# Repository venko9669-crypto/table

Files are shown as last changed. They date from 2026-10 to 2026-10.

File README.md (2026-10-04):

# Сгъваема (навиваща се) маса

## Маса

| Параметър | Стойност |
|---|---|
| Плот | 500 × 700 мм |
| Височина | 415 мм |
| Товар | ~10 кг (разпределени) |
| Маса | ~2.7 кг (с алуминиеви тръби) |
| Сгъната на квадрат | ~190 × 190 мм при звената (150 × 150 в средата) × ~704 мм, всичко вътре |
| Навита | Ø~230 мм × ~704 мм, всичко вътре |

## Тръби

| Част | Размер | Бр. | Рязане |
|---|---|---|---|
| Лайсни (плот) | Ø10 × 700 мм | 26 | не се режат |
| Заключващи тръби (рамо) | Ø10 × 547 мм, 2 дупки Ø4 на 535 мм една от друга (на 6 мм от краищата) | 2 | от 700, остатък 153 |
| Крака | Ø15 × 650 мм | 4 | не се режат |

Тънки: трябват 28 от 29 (1 резерва). Дебели: 4 от 4.
Разпънката между пивотите от стария дизайн вече не трябва.

## Печат (PETG)

Готовите STL файлове са в папка `stl/` (и в `table_stl.zip`), вече обърнати
както се печатат, без подпори. Общо ~0.9 кг PETG.

| STL | Част | Бр. | Запълване |
|---|---|---|---|
| `link_outer.stl` | жълто звено | 22 | 40% gyroid |
| `link_inner.stl` | синьо звено | 24 | 40% |
| `link_end.stl` | крайно звено с вилка | 2 | 40% gyroid |
| `link_end_r.stl` | огледалното | 2 | 40% gyroid |
| `leg_shoe.stl` | обувчица | 4 | 25% gyroid |
| `leg_hub.stl` | вложка в центъра | 1 | 15% gyroid |
| `leg_mount.stl` | скоба на лайсна | 2 | 50% gyroid |
| `leg_mount_r.stl` | огледалната | 2 | 50% gyroid |

Слой 0.2 мм, 4 стени (3 стигат за звената - спестява ~15%).
Преди серията отпечатай по 1 жълто и 1 синьо звено и пробвай с тръба
(пресовата сглобка, процепа и щракването на заключващата тръба).
Дребни части: 2 пина Ø4 (щифт или болт M4), 8 винта M3 (самонарезни) за скобите.

### Оптимизации за печат

По препоръките за FDM дизайн (фаски по ръбовете на масата на принтера,
заоблени вътрешни ъгли, без надвеси над 45°):

- фаска 45° по всички ръбове, които лягат на принтера - няма „слонски крак“;
  фаските са на стъпала по 0.2 мм, точно колкото слоя (`print_helpers.scad`);
- фаски на входа на всички отвори - тръбите влизат по-лесно, а първият слой
  не стеснява отвора;
- заоблени ъгли R2 на звената и R3 във вътрешните ъгли на синьото звено;
- синьото звено е плоско отдолу (шайбичката е само отгоре) - ляга цялото
  на принтера, вместо да стои на два пръстена;
- обувчицата е тънка плоча + тяло само колкото ръкава (-21% материал);
- вложката е по-малка (Ø92 × 40) и се печата с 15% запълване (-20%).
  Пробвах вариант само с ръкави около краката, но те висят под 54° и
  не се печатат без подпори - затова тя остава сплескана сфера.

## Сглобяване

1. Сините звена се пъхат в процепите на жълтите, после лайсната се вкарва
   отвътре през жълтото и синьото до дъното на гнездото.
2. Скобите `mount` са щипки: щракват се отдолу на лайсни №4, 6, 21 и 23
   (броено от 1 до 26) и се затягат с M3. Пробий малка вдлъбнатина (Ø2.5)
   в лайсната под всеки винт - кракът бута скобата по лайсната и винтът
   трябва да опира в нея, а не само да стиска.
3. Заключващата тръба се закача с пин на `end` и се щраква в каналите като цип.
   Вторият пин в `end_r` я заключва.
4. Краката минават през вложката, горе влизат в скобите, долу в обувчиците.

## Сгъване на квадрат

Плотът се сгъва с горната повърхност навътре, като 4 стави се сгъват на 90°:
при лайсни №3, 10, 17 и 24. Получава се кутия 140 × 140 мм по осите на
лайсните. Шевът (двете крайни звена с вилките) е по средата на едната страна.

1. Вади се заключващата тръба (двата пина) и краката.
2. Развиват се винтовете M3 и скобите се откачват от лайсните.
3. Вътре се прибират: краката в 4-те ъгъла, вложката в единия край,
   обувчиците една след друга по средата, скобите в другия край,
   заключващите тръби покрай стената.
4. Кутията се стяга с колан или ластик.

Проверено в модела (`folded.scad`): в ъглите звената от двете страни са на
1 мм едно от друго, шевът не се удря, а нещата вътре не опират в звената
и едно в друго (свободно между звената по дължина: 666 мм, краката са 650).
Може и да се навие на руло (`rolled.scad`), Ø~230 мм.

## Проверка

`python3 check_fit.py` пресмята дължините, височините, разминаването на
краката, стабилността, натоварването и навиването. Важните резултати:

- Ъгъл на краката 35.6°, кръстосване на 201 мм. Краката се разминават във
  вложката с 3.9 мм.
- Продължението на оста на всеки крак минава точно през оста на лайсната,
  на която е скобата, така кракът не усуква лайсната.
- Обувчиците имат „пета“ 70 мм навън. С нея масата се накланя при ~7 кг
  натиск върху самия ръб на дългата страна (без нея беше ~3 кг).
- Товароносимост (разпределен товар, до провлачване на тръбите):
  ~31 кг с алуминиеви тръби, ~50 кг със стоманени. Най-слабото място е
  късото парче лайсна между скобата на крака и веригата. С коефициент на
  сигурност 2: **~15 кг (алуминий) / ~25 кг (стомана)**.
- Една лайсна Ø10×1 мм от алуминий носи до ~5 кг **точков** товар в
  средата (стомана ~8 кг). Лайсните не си делят точков товар, но 10 кг
  разпределени по целия плот са само ~0.4 кг на лайсна.

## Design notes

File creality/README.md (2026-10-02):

# Плочи за Creality (маса 220 × 220 мм)

Отвори .3mf файловете в Creality Print (или Orca/Cura). Всяка плоча е
подредена и центрирана, частите са отделни обекти.

| Файл | Части | Запълване | Бележки |
|---|---|---|---|
| `plate1_links_outer.3mf` | 22 жълти + 2 end + 2 end_r | 40% gyroid | brim 5 мм (високи и тесни) |
| `plate2_links_inner.3mf` | 24 сини | 40% | |
| `plate3_shoes.3mf` | 4 обувчици | 25% gyroid | |
| `plate4_hub.3mf` | 1 вложка | 15% gyroid | |
| `plate5_mounts.3mf` | 2 mount + 2 mount_r | 50% gyroid | brim 8 мм (81 мм високи) |

Общо за всички: PETG, дюза 0.4, слой 0.2 мм, 4 стени, 5 горни/долни слоя,
без подпори. PETG: дюза 235-245 °C, маса 75-80 °C, вентилатор 30-50%.

Преди да пуснеш plate1 и plate2 изцяло - отпечатай по 1 жълто и 1 синьо
звено и пробвай с тръба.

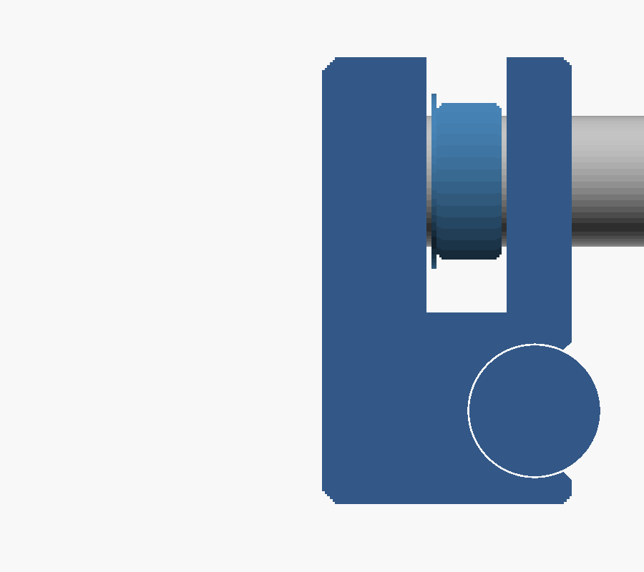
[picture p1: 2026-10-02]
chain_link_section.png

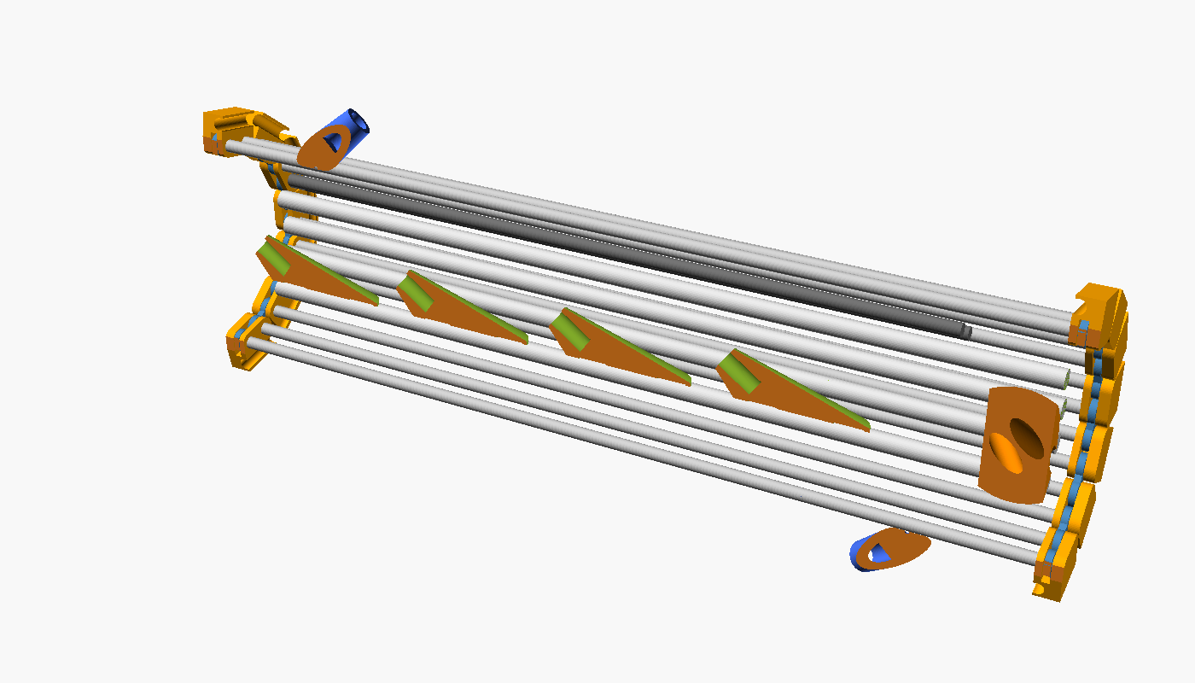
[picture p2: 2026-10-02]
rolled_cutaway.png

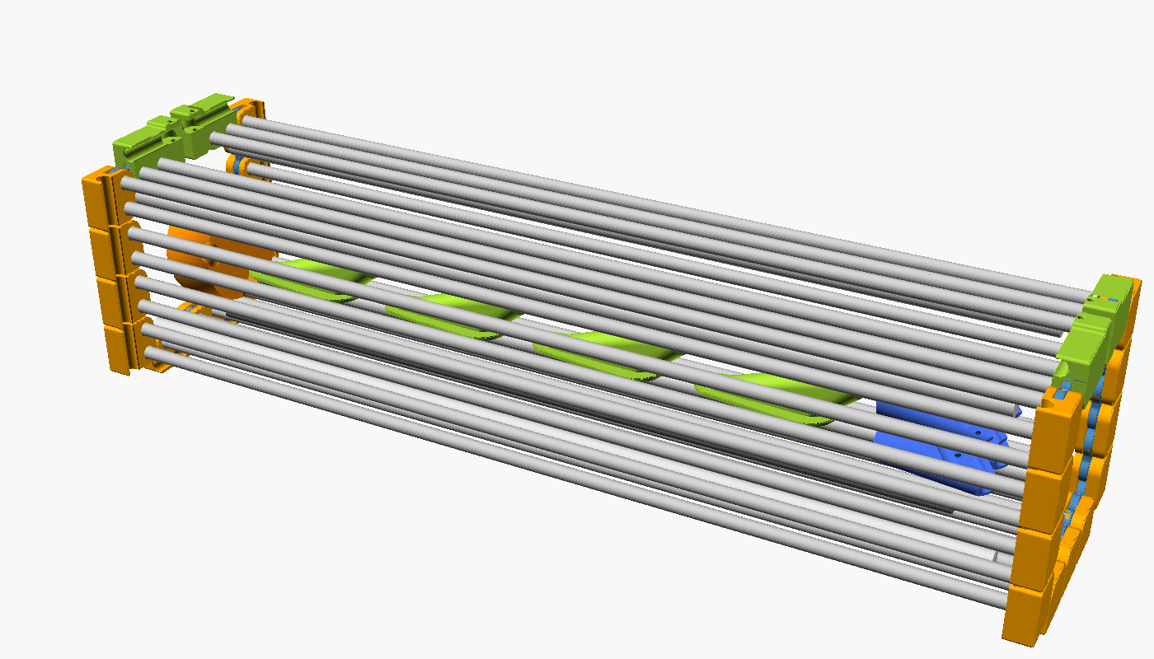
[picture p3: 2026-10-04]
folded.png

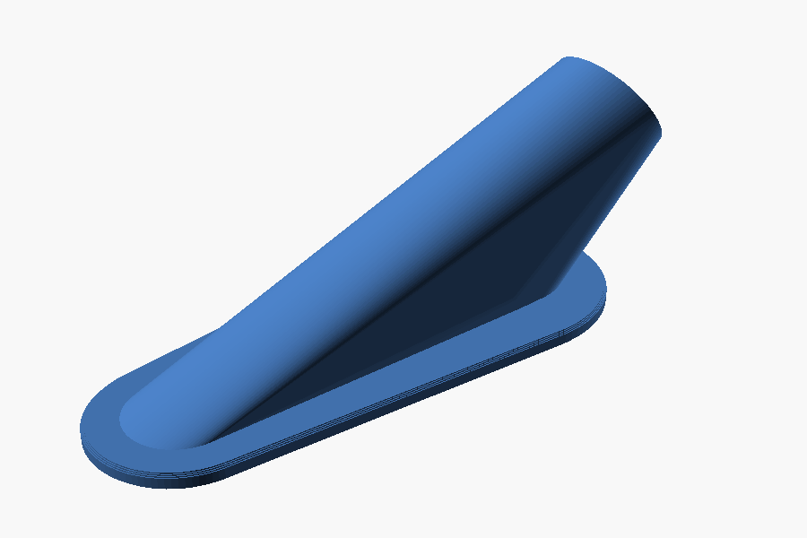
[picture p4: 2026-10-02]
legs_shoe.png

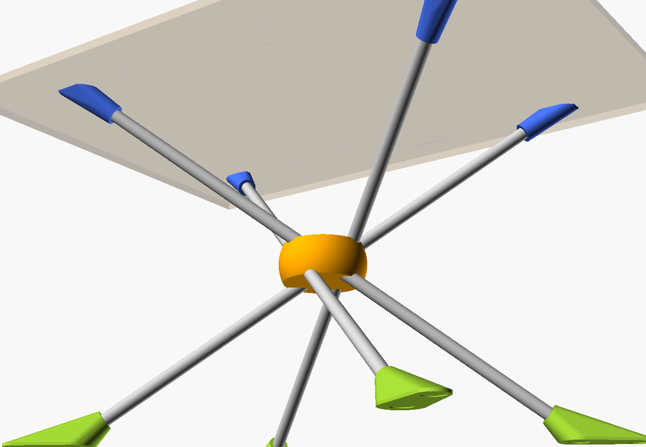
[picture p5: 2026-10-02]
legs.png

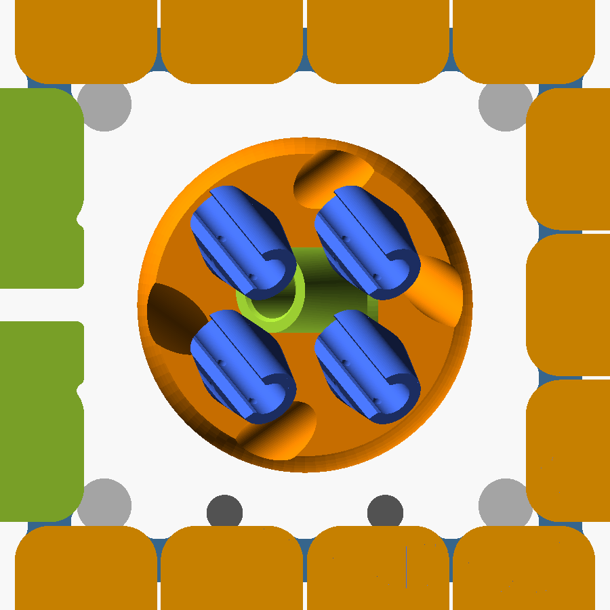
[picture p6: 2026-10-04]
folded_end.png

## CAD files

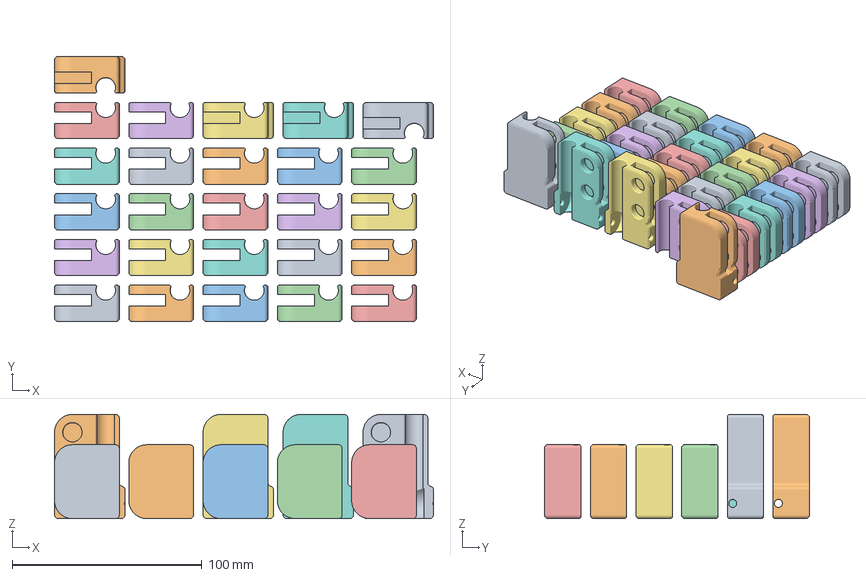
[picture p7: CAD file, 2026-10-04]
creality/plate1_links_outer.3mf
200.0 x 139.6 x 55.0 mm
link_outer_1
link_outer_2
link_outer_3
link_outer_4
link_outer_5
link_outer_6
link_outer_7
link_outer_8
link_outer_9
link_outer_10
link_outer_11
link_outer_12
link_outer_13
link_outer_14
link_outer_15
link_outer_16
link_outer_17
link_outer_18
link_outer_19
link_outer_20
link_outer_21
link_outer_22
link_end_1
link_end_2
link_end_r_1
link_end_r_2

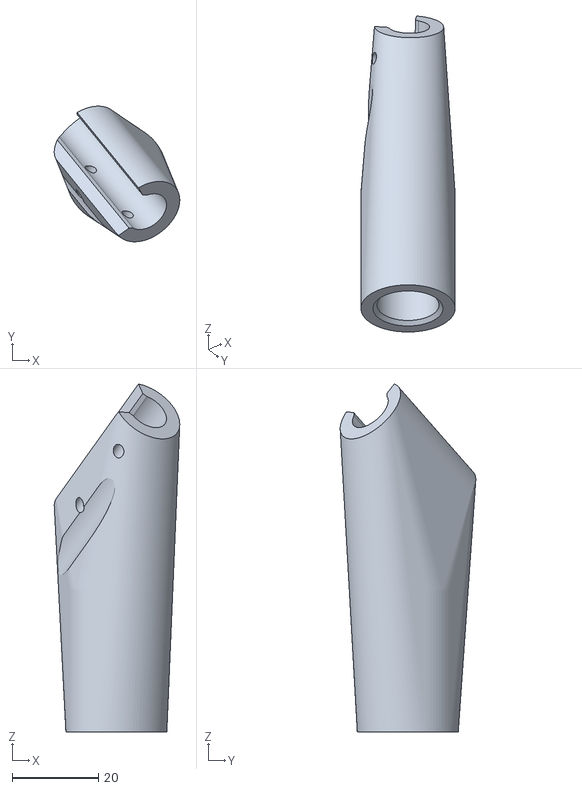
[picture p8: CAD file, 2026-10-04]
stl/leg_mount.stl
29.1 x 31.4 x 80.6

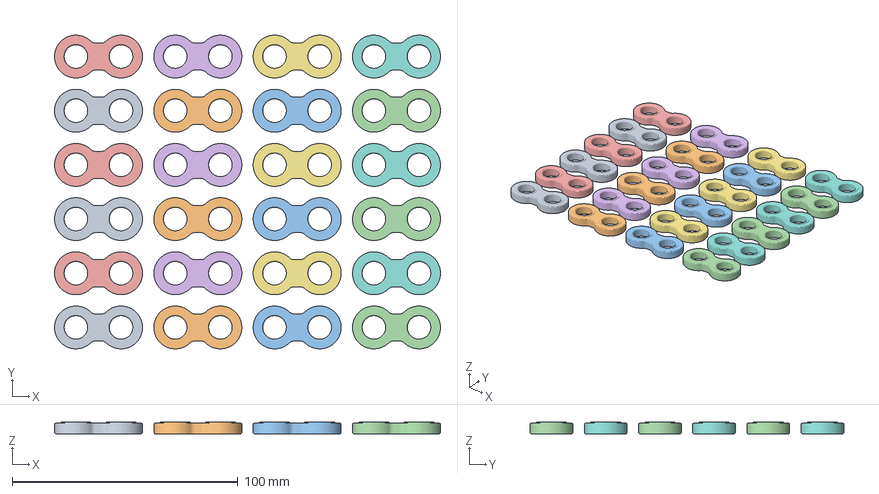
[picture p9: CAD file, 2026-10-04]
creality/plate2_links_inner.3mf
171.0 x 139.0 x 5.40 mm
link_inner_1
link_inner_2
link_inner_3
link_inner_4
link_inner_5
link_inner_6
link_inner_7
link_inner_8
link_inner_9
link_inner_10
link_inner_11
link_inner_12
link_inner_13
link_inner_14
link_inner_15
link_inner_16
link_inner_17
link_inner_18
link_inner_19
link_inner_20
link_inner_21
link_inner_22
link_inner_23
link_inner_24

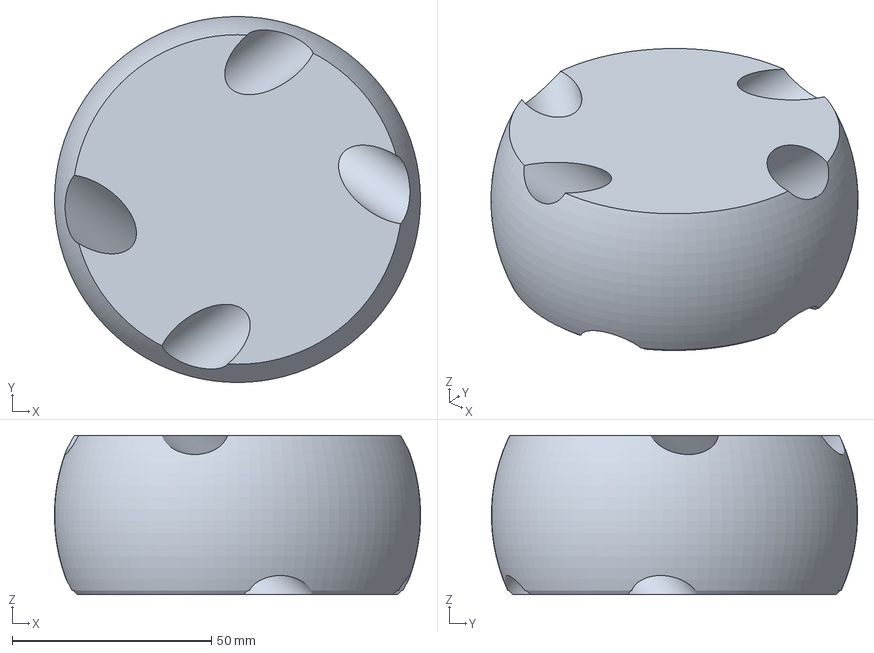
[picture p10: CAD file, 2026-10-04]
creality/plate4_hub.3mf
92.0 x 92.0 x 40.0 mm

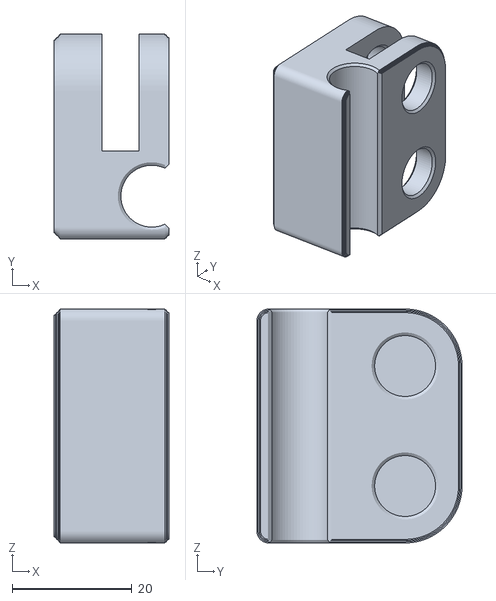
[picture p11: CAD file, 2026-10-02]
stl/link_outer.stl
19.1 x 34.2 x 39.0

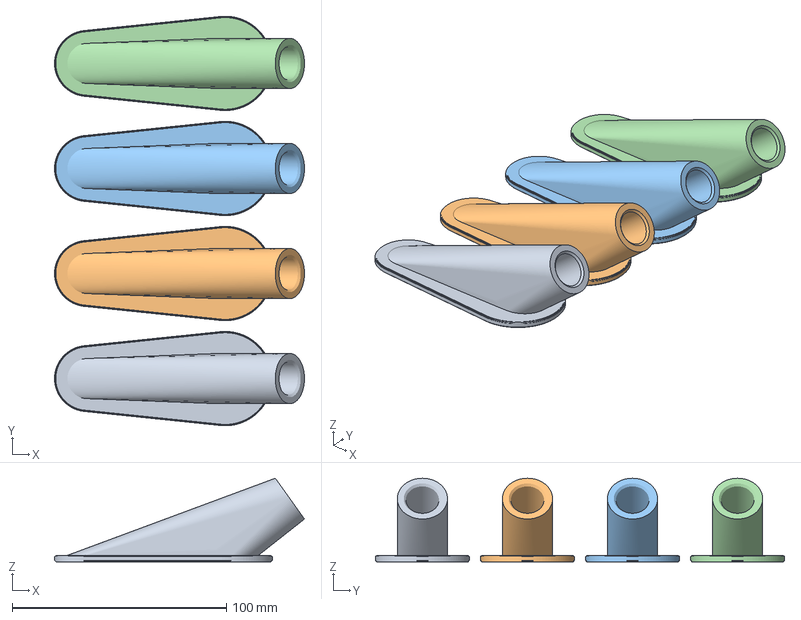
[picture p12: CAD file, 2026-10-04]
creality/plate3_shoes.3mf
116.6 x 191.0 x 39.0 mm
leg_shoe_1
leg_shoe_2
leg_shoe_3
leg_shoe_4

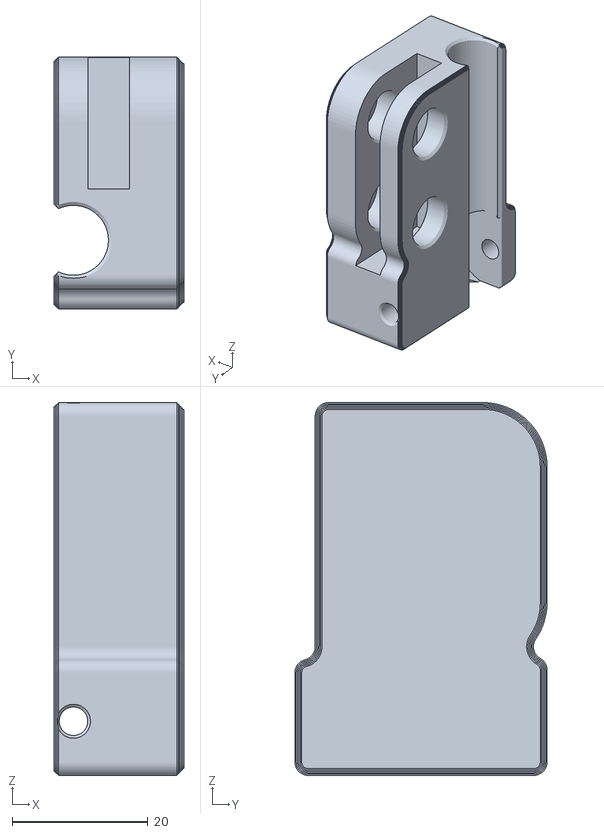
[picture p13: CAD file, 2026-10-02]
stl/link_end_r.stl
19.1 x 37.2 x 55.0

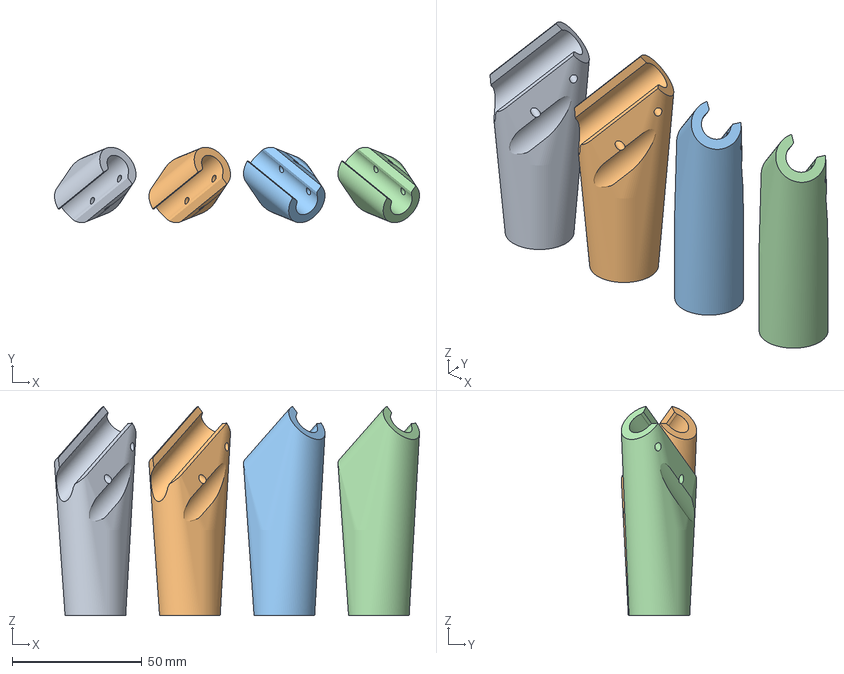
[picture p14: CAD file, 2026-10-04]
creality/plate5_mounts.3mf
140.7 x 29.1 x 80.6 mm
leg_mount_1
leg_mount_2
leg_mount_r_1
leg_mount_r_2

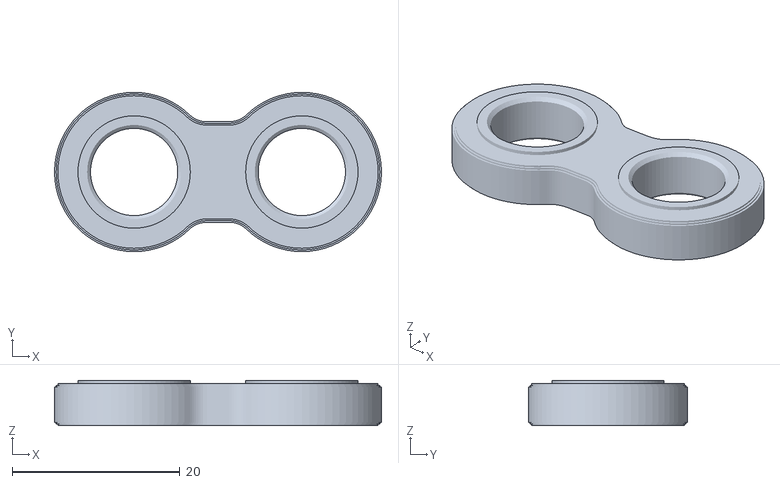
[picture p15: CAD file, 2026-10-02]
stl/link_inner.stl
39.0 x 19.0 x 5.40

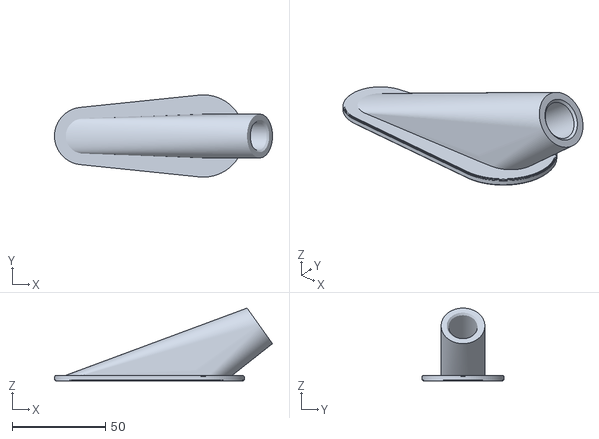
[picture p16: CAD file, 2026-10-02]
stl/leg_shoe.stl
116.6 x 44.0 x 39.0

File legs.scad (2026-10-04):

// Краката на масата: 4 тръби Ø15 x 650, кръстосани в центъра на масата
// по средата на височината.
//
// Всеки крак тръгва от стъпало (обувчица) на пода, минава през центъра на
// масата и стига под противоположния ъгъл на плота. В центъра 4-те крака
// минават през вложка (hub) с 4 наклонени отвора.
//
// Четири оси не могат да минат през една и съща точка, без тръбите да се
// пресекат. Затова всеки крак е изместен встрани от центъра с hub_e, а
// посоката на изместването се върти в една и съща посока (като стол с
// усукани крака). Така краката се разминават в центъра, а горе и долу
// все още гледат към ъглите (отклонението е само hub_e).
//
//   Отгоре:                  Отстрани (по диагонала):
//
//    ъгъл .         . ъгъл          плот ____________
//           \     /                      \        /
//            [hub]                         \    /
//           /     \                         [hub]   <- средата на височината
//    стъпало        стъпало                /    \
//                                   стъпало      стъпало
//
// Части:
//   shoe    - обувчица на долния край на крака (плоско дъно, наклонено гнездо)
//   hub     - вложката в центъра с 4 отвора
//   mount   - скоба-щипка: щраква се на лайсна от плота отдолу, със сляпо
//             наклонено гнездо за горния край на крака. mount_r е огледалната
//             (по 2 от всяка). При сгъване се свалят и се прибират вътре.
//
// Горните краища не стигат до звената на ръба (половин крак е 325 мм, а ръбът
// е на 350 мм от центъра), затова скобите хващат лайсни на ~170-220 мм от центъра.
// hub_e и mount_drop са избрани така, че продължението на оста на всеки крак
// да минава точно през оста на лайсна - тогава кракът не усуква лайсната.
// Печат: shoe - на плоското дъно; hub - на плоската долна страна;
//        mount - на устието на гнездото (то е плоско). Без подпори.

include <print_helpers.scad>

$fn = 96;

/* [Маса] */
table_w = 700;    // плот по X
table_d = 500;    // плот по Y
table_h = 415;    // височина до горната повърхност на плота (= горната страна на лайсните)
slat_d  = 10;     // лайсни на плота
slat_pitch = 20;
n_slats = 26;

/* [Крака] */
leg_d   = 15;     // диаметър на крака
leg_len = 650;    // дължина на крака
tol     = 0.4;    // хлабина на отворите за крака

/* [Обувчица] */
shoe_z     = 12;  // височина на оста на крака в края му над пода
shoe_sock  = 30;  // дълбочина на гнездото по оста
shoe_wall  = 4;   // стена около крака
shoe_pad_d = 44;  // диаметър на стъпката
shoe_pad_h = 3;   // дебелина на стъпката
pad_recess = 0.8; // вдлъбнатина отдолу за гумено/филцово лепенче (0 = без)
shoe_toe   = 70;  // колко навън (към ъгъла) продължава стъпката - разширява базата
shoe_plate = 3;   // дебелина на плочата на стъпката (под ребрата)

/* [Скоба на лайсна] */
mount_drop = 20;  // колко под оста на лайсната е горният край на оста на крака
                  // (20 мм дава ос на крака, която минава точно през оста на лайсната)
mount_sock = 30;  // дълбочина на гнездото за крака
mount_floor = 3;  // дъно на гнездото
mount_wall = 4;   // стена около крака
collar_len = 30;  // дължина на яката по лайсната
collar_wall = 3.5; // стена около лайсната
tol_slat   = 0.2; // хлабина на яката
clip_open  = 9.4; // отвор на щипката отгоре (< лайсната, за да щраква)
screw_d    = 2.8; // отвор за винт M3 (самонарезен), фиксира скобата на лайсната
nb_clr     = 1.5; // хлабина до съседните лайсни
hole_cham  = 0.5; // фаска на входа на отворите

/* [Вложка в центъра] */
hub_e = slat_pitch / cos(atan2(table_d/2, table_w/2));  // изместване (разминаване); така горните краища падат под лайсни
hub_r = 46;       // радиус на сферата, от която е изрязана вложката
hub_h = 40;       // височина на вложката (плоска отгоре и отдолу)

/* [Изглед] */
part = "assembly"; // [shoe, hub, mount, mount_r, assembly]

// --- изчислени ---
slat_z = table_h - slat_d/2;                        // ос на лайсните
leg_top_z = slat_z - mount_drop;
alpha = asin((leg_top_z - shoe_z) / leg_len);       // ъгъл на крака спрямо пода
cross_z = (leg_top_z + shoe_z) / 2;                 // височина на кръстосването
phi0 = atan2(table_d/2, table_w/2);                 // посока към ъгъла
phis = [phi0, 180 - phi0, 180 + phi0, -phi0];       // посоки към 4-те ъгъла (горния край)
half_h = leg_len/2 * cos(alpha);                    // хоризонтално от центъра до края

// Посока на крака (нагоре към ъгъла)
function leg_dir(phi) = [cos(alpha)*cos(phi), cos(alpha)*sin(phi), sin(alpha)];
// Горният край на крака с ъгъл phi
function leg_top(phi) = [-hub_e*sin(phi) + half_h*cos(phi), hub_e*cos(phi) + half_h*sin(phi), leg_top_z];
// Продължението на оста на крака пресича височината на лайсните тук.
// Скобата се поставя там, така силата от крака минава през оста на лайсната
// и не я усуква.
k_top = mount_drop / sin(alpha);
function leg_at_slat(phi) = leg_top(phi) + k_top * leg_dir(phi);
// Най-близката лайсна (лайсните са центрирани около y = 0)
y0_slat = -(n_slats - 1) * slat_pitch / 2;
function slat_y(y) = y0_slat + round((y - y0_slat) / slat_pitch) * slat_pitch;
S0 = leg_at_slat(phis[0]);
S1 = leg_at_slat(phis[1]);
mount_dy = S0[1] - slat_y(S0[1]);                   // остатъчно разминаване с лайсната
assert(abs((S1[1] - slat_y(S1[1])) - mount_dy) < 0.01,
       "Краката не падат симетрично под лайсни - провери hub_e");
assert(abs(mount_dy) < 2, "Оста на крака не попада на лайсна - нагласи mount_drop");

echo(str("Скоби: на лайсни y = ", slat_y(S0[1]), " и ", slat_y(S1[1]),
         ", на x = ±", S0[0], " и ±", -S1[0], " мм от центъра; dy = ", mount_dy));
echo(str("Ъгъл на краката: ", alpha, "°; кръстосване на ", cross_z, " мм; ",
         "краищата на ", half_h, " мм от центъра (хоризонтално)"));

// Ориентира оста z по крака, който отива нагоре към ъгъл phi
module along_leg(phi) rotate([0, 90 - alpha, phi]) children();

// Ос на крак i: минава през (hub_e * нормалата, cross_z) с посока нагоре към ъгъла
module leg_frame(phi) {
    translate([-hub_e * sin(phi), hub_e * cos(phi), cross_z]) along_leg(phi) children();
}

// ---------------- Обувчица ----------------
// Локално: оста на крака се издига към +x, долният ѝ край е в (0, 0, shoe_z).
module shoe() {
    sock_d = leg_d + tol;
    body_d = sock_d + 2*shoe_wall;
    // къде оста на крака стига пода - там центрираме стъпката
    x_floor = -shoe_z / tan(alpha);
    xs = [x_floor + shoe_pad_d/4, -shoe_toe];         // предна и задна част на стъпката
    module pad_2d() hull() {
        translate([xs[0], 0]) circle(d = shoe_pad_d);
        translate([xs[1], 0]) circle(d = shoe_pad_d * 0.7);
    }
    difference() {
        union() {
            // тънка плоча на стъпката, с фаска отдолу
            cext(shoe_plate, cb = 0.6, ct = 0.6) pad_2d();
            // тяло само колкото ръкава: вертикални стени от плочата до гнездото
            intersection() {
                hull() {
                    translate([xs[1], 0, 0]) cylinder(d = body_d * 0.8, h = shoe_plate);
                    translate([xs[0], 0, 0]) cylinder(d = body_d, h = shoe_plate);
                    translate([0, 0, shoe_z]) rotate([0, 90 - alpha, 0])
                        translate([0, 0, -body_d/2]) cylinder(d = body_d, h = shoe_sock + body_d/2);
                }
                translate([-200, -200, 0]) cube([400, 400, 200]);   // плоско дъно
            }
        }
        // гнездо за крака, с фаска на входа
        translate([0, 0, shoe_z]) rotate([0, 90 - alpha, 0]) {
            cylinder(d = sock_d, h = shoe_sock + 50);
            translate([0, 0, shoe_sock + 0.01]) mirror([0, 0, 1]) hole_chamfer(sock_d, 1);
        }
        // вдлъбнатини за лепенца
        if (pad_recess > 0) for (i = [0, 1])
            translate([xs[i], 0, -1]) cylinder(d = (i == 0 ? shoe_pad_d : shoe_pad_d * 0.7) - 8, h = pad_recess + 1);
    }
}

// ---------------- Вложка ----------------
// Локално: центърът на кръстосването е в (0, 0, 0).
// Сплескана сфера: стените ѝ са под <45° от вертикалата, печата се без
// подпори. Вътрешността я олекотява слайсърът (15-20% gyroid запълване).
module hub() {
    difference() {
        intersection() {
            sphere(r = hub_r);
            cube([3*hub_r, 3*hub_r, hub_h], center = true);
        }
        for (phi = phis) translate([0, 0, -cross_z]) leg_frame(phi) {
            cylinder(d = leg_d + tol, h = 3*hub_r, center = true);
        }
        // фаска по долния ръб (ляга на принтера)
        translate([0, 0, -hub_h/2 - 0.01]) difference() {
            cylinder(r = hub_r, h = 1);
            cylinder(r1 = sqrt(hub_r^2 - (hub_h/2)^2) - 0.8, r2 = sqrt(hub_r^2 - (hub_h/2)^2) + 0.2, h = 1);
        }
    }
}
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

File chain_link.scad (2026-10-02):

// Звено "осмица" - свързва краищата на тънките тръби като верига на колело.
// Тръбите са нитовете, плочките са звената.
//
// Две части:
//   outer (жълта) - едно цяло: външна плочка A (сляпо гнездо, капаче) + вътрешна
//                   плочка B + "ботуш" отдолу, който ги свързва и носи полуотворения
//                   канал за заключващата тръба. Стяга тръбите (пресова сглобка).
//   inner (синя)  - влиза в процепа между A и B, върти се свободно около тръбата.
//   end   (зелена)- крайно звено в началото и в края на веригата: като жълтото, но
//                   с удължение - вилка с пин. В началото пинът минава през дупка
//                   в заключващата тръба и тя се върти около него като рамо.
//                   В края втори пин минава през другата дупка и я заключва.
//                   end_r е огледалното за другия край.
//
//   Изглед отстрани (ос на тръбите е към теб), плотът е отгоре:
//
//   тръби:                0     1     2     3     4     5
//   звена:               [0===1][1===2][2===3][3===4][4===5]
//   ботуши:          [end=======]   [outer]     [=======end_r]
//   заключваща тръба:   o=============================o
//                       ^ пин (ос, рамото се върти)   ^ пин (заключва)
//
//   Отгоре (плотът е нагоре по екрана):  рамото се завърта около първия пин
//   и щраква последователно в каналите, като ципа; накрая вторият пин.
//
// Сглобяване: синята плочка се пъха в процепа на две съседни жълти, после
// тръбата се вкарва отвътре през B и синята до дъното на гнездото в A.
// След като масата се разпъне, заключващата тръба се щраква странично (откъм
// вътрешността на масата) в каналите на всички outer звена - тя изправя
// веригата в права линия и плотът не се огъва.
//
//   Сечение на outer (гледа се по дължината на веригата):
//
//     навън               навътре (към плота)
//       |‾‾‾‾‾‾‾‾‾‾‾‾‾‾‾‾‾|
//       | ///// |inner| B |  <- тръба на плота
//       |‾‾‾‾‾‾‾‾‾‾‾‾‾‾‾‾‾
//       |            __
//       |           (     <- заключваща тръба, щраква отдясно
//       |____________‾‾      (отворът е по-тесен от тръбата)
//
// По двата ръба на плота - огледално.
// Плотът се сгъва нагоре (горната повърхност навътре); надолу го спират ботушите.
// Печат: outer и end - изправени на тесния край (каналът и процепът са
//        вертикални), inner - плоско. Без подпори.

include <print_helpers.scad>

$fn = 64;

/* [Тръби] */
tube_d = 10;       // диаметър на тънката тръба
pitch  = 20;       // стъпка център-в-център

/* [Звено] */
t          = 5;    // дебелина на една плочка (B и inner)
wall       = 4.5;  // стена около тръбата (ухо Ø19 при стъпка 20)
waist      = 12;   // ширина на "талията" между двата отвора
gap        = 1;    // хлабина между съседни звена в един слой
tol_press  = 0.15; // хлабина на отворите при outer (стяга тръбата)
tol_free   = 0.4;  // хлабина на отвора при inner (върти се)
spacer     = 0.4;  // шайбичка около отвора на inner (от горната страна)
slot_clr   = 0.3;  // хлабина на inner в процепа на outer (общо)

/* [Заключване] */
lock_d     = 10;   // диаметър на заключващата тръба
tol_lock   = 0.3;  // хлабина на канала (диаметър)
snap_open  = 8.6;  // ширина на отвора на канала (< lock_d, за да щраква)
lead_in    = 1;    // скосяване на входа на канала
sock       = 6;    // дълбочина на слепото гнездо за тръбата в плочка A
cap_t      = 2;    // капаче над гнездото (външната страна)
clr        = 0.5;  // хлабина между ботуша и ушите на inner/B
ch_wall    = 2.4;  // стена над канала (носи натиска от заключващата тръба)
lip_wall   = 2;    // стена под канала (устната, която щраква)

/* [Крайно звено (рамо)] */
ext        = 16;   // удължение на ботуша навън от веригата (вилката)
pin_d      = 4;    // пин (стоманен щифт или болт M4); същата дупка в заключващата тръба
tol_pin    = 0.2;  // хлабина на отвора за пина
stub       = 6;    // колко стърчи заключващата тръба зад пина
fork_extra = 3;    // удебеляване на долната стена на вилката

/* [Печат] */
edge_r     = 2;    // заобляне на ъглите
cham_out   = 1;    // фаска на външната страна (капачето)
cham_in    = 0.6;  // фаска на вътрешната страна и по ръбовете
hole_cham  = 0.5;  // фаска на входа на отворите

/* [Изглед] */
part    = "assembly"; // [outer, inner, end, end_r, assembly]
n_tubes = 6;          // за assembly
arm_angle = 0;        // за assembly: ъгъл на отвореното рамо (0 = заключено)

lobe_d = min(tube_d + 2*wall, pitch - gap);   // външен диаметър на "ухото"
ch_d   = lock_d + tol_lock;                   // диаметър на канала
layer_inner = t + 2*spacer;                   // място за inner слоя (плочка + шайбичка + луфт)
t_A    = sock + cap_t;                        // дебелина на плочката A
slot   = layer_inner + slot_clr;              // процеп между A и B
boot_in = slot + t;                           // колко навътре стига outer (до края на B)
z_B    = -boot_in;                            // B: от z_B до z_B + t
y_top  = -lobe_d/2 - clr;                     // горен ръб на ботуша (под ушите)
ch_cy  = y_top - ch_wall - ch_d/2;            // ос на канала (височина)
ch_o   = sqrt((ch_d/2)^2 - (snap_open/2)^2);  // колко навътре в ботуша е оста на канала
ch_cz  = -boot_in + ch_o;                     // ос на канала (по оста на тръбите)
y_bot  = ch_cy - ch_d/2 - lip_wall;           // долен ръб на ботуша

assert(lobe_d - tube_d >= 3, "Стената е твърде тънка - увеличи pitch или намали tube_d");
assert(waist <= lobe_d, "waist трябва да е <= lobe_d");
echo(str("Заключваща тръба при 26 тръби на плота: дупки през ", 25*pitch - 2*x_pin,
          " мм (център-център), обща дължина ", 25*pitch - 2*x_pin + 2*stub, " мм"));
assert(snap_open < lock_d, "snap_open трябва да е по-малко от lock_d, иначе няма щракване");
x_pin  = -lobe_d/2 - ext/2;                   // ос на пина (в началния край)
R_stub = sqrt(stub^2 + (ch_d/2)^2) + 0.5;     // радиус, който описва опашката на рамото
assert(stub <= ext/2 - 1, "stub е твърде дълъг за ext");
assert(ch_cz + R_stub + 1.6 <= t_A, "Опашката на рамото пробива задната стена - намали stub");
assert(ch_cz + ch_d/2 + 1.6 <= t_A, "Ботушът е твърде тесен за канала - увеличи t или sock");

// Плосък контур на осмицата (без отвори)
module eight_2d() {
    circle(d = lobe_d);
    translate([pitch, 0]) circle(d = lobe_d);
    translate([0, -waist/2]) square([pitch, waist]);
}

// Плосък контур "стадион" - за плочките на outer
module stadium_2d() {
    hull() { circle(d = lobe_d); translate([pitch, 0]) circle(d = lobe_d); }
}

module holes(hole_d, z0, h) {
    for (x = [0, pitch]) translate([x, 0, z0]) cylinder(d = hole_d, h = h);
}

// Контур (по XY) на жълтото/крайното звено: горе ушите, долу ботушът.
// ext_l > 0 добавя удължение навън за вилката на крайното звено.
module link_profile(ext_l = 0) {
    L = pitch + lobe_d;
    round2d(edge_r, edge_r) {
        stadium_2d();
        translate([-lobe_d/2, y_bot]) square([L, -y_bot]);
        if (ext_l > 0) {
            yb = y_bot - fork_extra;
            translate([-lobe_d/2 - ext_l, yb]) square([ext_l + 1, lobe_d/2 - yb]);
        }
    }
}

// Общото тяло на жълтото и крайното звено.
// z=0 е вътрешната страна на A, тръбите идват от -z.
// A: z 0..t_A (сляпо гнездо + капаче навън); процеп за inner; B: z_B..z_B+t.
module link_body(ext_l = 0) {
    L = pitch + lobe_d;
    difference() {
        translate([0, 0, z_B]) cext(boot_in + t_A, cb = cham_in, ct = cham_out) link_profile(ext_l);
        // процеп за синята плочка (над ботуша)
        translate([-lobe_d/2 - (ext_l > 0 ? 0 : 1), y_top, -slot]) cube([L + 2, 50, slot]);
        // гнезда в A (с фаска на входа откъм процепа)
        for (x = [0, pitch]) translate([x, 0, 0]) {
            translate([0, 0, -1]) cylinder(d = tube_d + tol_press, h = sock + 1);
            hole_chamfer(tube_d + tol_press, hole_cham);
        }
        // отвори в B (с фаски от двете страни)
        for (x = [0, pitch]) translate([x, 0, z_B]) {
            translate([0, 0, -1]) cylinder(d = tube_d + tol_press, h = t + 2);
            hole_chamfer(tube_d + tol_press, hole_cham);
            translate([0, 0, t]) mirror([0, 0, 1]) hole_chamfer(tube_d + tol_press, hole_cham);
        }
        // полуотворен канал по дължина на веригата, отворът гледа към плота (-z)
        translate([-lobe_d/2 - ext_l - 1, ch_cy, ch_cz]) rotate([0, 90, 0])
            cylinder(d = ch_d, h = L + ext_l + 2);
        // фаски на канала в двата края (по тях звеното ляга на принтера)
        for (x = [-lobe_d/2, pitch + lobe_d/2]) if (!(ext_l > 0 && x < 0))
            translate([x, ch_cy, ch_cz]) rotate([0, x < 0 ? 90 : -90, 0]) hole_chamfer(ch_d, hole_cham);
        // скосен вход, за да се щраква по-лесно
        translate([-lobe_d/2 - ext_l - 1, ch_cy, -boot_in]) rotate([90, 0, 90])
            linear_extrude(L + ext_l + 2) polygon([
                [-snap_open/2 - lead_in, -0.01], [snap_open/2 + lead_in, -0.01],
                [snap_open/2, lead_in], [-snap_open/2, lead_in]]);
    }
}
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

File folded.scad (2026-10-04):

// Масата, сгъната на квадрат: горната повърхност е навътре, 4 стави са
// сгънати на 90°. Краката, вложката, обувчиците, скобите и заключващите
// тръби са прибрани вътре. Само за изглед - не се печата.

use <chain_link.scad>
use <legs.scad>

$fn = 48;

/* [Изглед] */
show_contents = true;   // краката и останалото вътре
cutaway = false;        // разрязано наполовина, за да се види вътре
check = -1;             // 0..3 - проверка за удар в ъгъл №check (празно = няма удар)

// стойности от chain_link.scad / legs.scad
pitch = 20; n = 26; tube_d = 10; slat_len = 700;
sock = 6;                     // лайсната влиза 6 мм в плочка A
z_inner = -6.1 + (6.1 - 5.4)/2;   // мястото на синята плочка в процепа

// Квадрат 7 x 7 стъпки (140 x 140 мм по осите на лайсните): 28 позиции,
// 26 лайсни + 3 стъпки шев между крайните звена (51 мм с вилките + 9 мм луфт).
side = 7;
half = side * pitch / 2;
corners_slat = [2, 9, 16, 23];        // лайсните, на които се сгъва на 90°
function pos(j) = (j + 26) % 28;      // лайсна 0 е на позиция 26 (шевът е на лявата страна)
function Pp(p) =
    p <= side     ? [-half + p * pitch, -half] :
    p <= 2*side   ? [ half, -half + (p - side) * pitch] :
    p <= 3*side   ? [ half - (p - 2*side) * pitch,  half] :
                    [-half,  half - (p - 3*side) * pitch];
function P(j) = Pp(pos(j));
function ang(j) = let(d = P(j + 1) - P(j)) atan2(d[1], d[0]);

// Звено, което започва от лайсна j; локално +y сочи навътре в кутията
module at_link(j) translate([P(j)[0], P(j)[1], 0]) rotate([0, 0, ang(j)]) children();

module link(i) at_link(i)
    if (i % 2 == 1)      color("steelblue") translate([0, 0, z_inner]) inner_link();
    else if (i == 0)     color("yellowgreen") end_link();
    else if (i == n - 2) color("yellowgreen") end_link_r();
    else                 color("orange") outer_link();

module chain() for (i = [0 : n - 2]) link(i);

module slat(j) color("silver") translate([P(j)[0], P(j)[1], sock - slat_len]) cylinder(d = tube_d, h = slat_len);

module folded_table() {
    chain();
    translate([0, 0, 2*sock - slat_len]) mirror([0, 0, 1]) chain();
    for (j = [0 : n - 1]) slat(j);
}

// Всичко, което се прибира вътре
module contents() {
    z0 = sock - slat_len + 23;           // свободно между звената: 666 мм, краката са 650
    c = half - 5 - 1 - 7.5 - 1.5;     // крака в 4-те вътрешни ъгъла
    for (sx = [-1, 1], sy = [-1, 1]) color("lightgray")
        translate([sx * c, sy * c, z0]) cylinder(d = 15, h = 650);
    // вложката в единия край
    color("darkorange") translate([0, 0, z0 + 25]) hub();
    // заключващите тръби по долната стена
    for (x = [-22, 22]) color("dimgray") translate([x, -c - 2, z0 + 75]) cylinder(d = 10, h = 547);
    // 4 обувчици една след друга
    for (k = [0 : 3]) color("yellowgreen")
        translate([20, 4, z0 + 60 + k * 125]) rotate([0, -90, 0]) translate([75, 0, 0]) shoe();
    // 4 скоби в другия край
    for (k = [0 : 3]) color("royalblue")
        translate([(k % 2) * 34 - 17, floor(k / 2) * 34 - 17, z0 + 560]) mount_print();
}

module scene() {
    folded_table();
    if (show_contents) contents();
}

// Проверка: всичко около ъгъла k (звената и лайсните от двете страни) не се пресича
module corner_check(k) {
    c = corners_slat[k];
    intersection() {
        union() { link(c - 2); link(c - 1); slat(c - 1); slat(c - 2); }
        union() { link(c); link(c + 1); slat(c + 1); slat(c + 2); }
    }
}

if (check == -2) echo(); else if (check >= 0) corner_check(check);
else rotate([0, 90, 0]) translate([0, 0, slat_len/2 - sock])
    if (cutaway) difference() { scene(); translate([-500, 0, -1000]) cube([1000, 500, 2000]); }
    else scene();

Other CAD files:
stl/leg_mount_r.stl
stl/link_end.stl
stl/leg_hub.stl
print_helpers.scad
rolled.scad

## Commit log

2026-10-02 Keep only table and tube dimensions
    Claude-Session: https://claude.ai/code/session_011cUnhzAFGP7E1nGHqXwy9v
2026-10-02 Add chain-style link for joining tube ends
    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
    [chain_link.scad]
2026-10-02 Add lock plate with channel for a lengthwise locking tube
    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
    [chain_link.scad]
2026-10-02 Move lock channel under the tubes on the inner side
    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
    [chain_link.scad]
2026-10-02 Make lock channel half-open so the locking tube snaps in from the side
    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
    [chain_link.scad]
2026-10-02 Merge outer plates and lock boot into one rigid part
    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
    [chain_link.scad]
2026-10-02 Add end link with pin fork so the lock tube swings in as an arm
    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
    [chain_link.scad]
2026-10-02 Add leg shoe and center hub for crossed legs
    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
    [legs.scad]
2026-10-02 Add slat-clamp mount for the top end of the legs
    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
    [legs.scad]
2026-10-02 Strengthen links, align leg axes with slats, widen shoes, add fit check
    - Yellow/blue links: thicker plates (5 mm), 19 mm lobes, wider waist,
    deeper socket, thicker cap and channel wall
    - Leg axis now passes through the slat axis so the leg does not twist it
    - Mount clears neighbouring slats
    - Shoes get a 70 mm outward toe for a wider base
    - check_fit.py computes tube lengths, heights, leg clearance, stability,
    strength and rolled-up size
    - README: full parts list, assembly and roll-up notes
    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
    [chain_link.scad, legs.scad]
2026-10-02 Add rolled-up view of the table with legs stored inside
    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
    [rolled.scad]
2026-10-02 Export print-ready STLs, add load capacity estimate
    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
    [chain_link.scad, leg_hub.stl, leg_mount.stl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]
2026-10-02 Optimize parts for FDM printing: chamfers, fillets, lighter shoe and hub
    - print_helpers.scad: 2D rounding, layer-stepped 45° chamfers, hole chamfers
    - Links: rounded profile, chamfered faces and hole entries; blue link flat
    on the bed with the spacer on top only
    - Shoe: thin plate plus sleeve-width body instead of a solid wedge
    - Hub: smaller self-supporting sphere with a bed chamfer
    - Mount: chamfered socket mouth and collar
    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
    [chain_link.scad, leg_hub.stl, leg_mount.stl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]
2026-10-02 Add print-ready Creality plates (220x220) as 3MF
    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
    [plate1_links_outer.3mf, plate2_links_inner.3mf, plate3_shoes.3mf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]
2026-10-02 Fix leg mount: slat hole now runs through the whole part
    The slat hole was only as long as the collar (30 mm), but the body toward
    the leg socket extends ~9 mm further and blocked the slat.
    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
    [leg_mount.stl, leg_mount_r.stl, legs.scad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]
2026-10-04 Fold into a square box; snap-on leg mounts stored inside
    - folded.scad: table folded top-in at 4 joints (slats 3, 10, 17, 24) into
    a 140 x 140 mm box with legs, hub, shoes, mounts and lock tubes inside;
    corner and seam collision checks
    - Leg mount collar is now a snap-on clip, open on top, so mounts come off
    the slats by hand when folding
    - check_fit.py: square-fold section; README: folding steps
    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
    [folded.scad, leg_mount.stl, leg_mount_r.stl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]
2026-10-04 Folded view: move stored legs clear of the far-end links
    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
    [folded.scad]
